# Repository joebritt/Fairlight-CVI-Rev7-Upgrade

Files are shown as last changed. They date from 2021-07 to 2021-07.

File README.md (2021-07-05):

# Fairlight-CVI-Rev7-Upgrade
Board set to upgrade a Rev5 Fairlight CVI to Rev7. This upgrade also eliminates the need for backup batteries.

See overview and installation guide [here](https://docs.google.com/document/d/1melksT-DwwU80pforqxVVXWFiSj0hJ2Gdj74KaH-A6M/edit?usp=sharing).

### All PCB designs were done in Eagle.

There are 4 different PCBs:</br>

One is the actual CVI06A, which mounts to the rear of the CVI. It is substantially smaller than the original CVI06.</br>

One is a small board which replaces the SRAM inside the CVI. This new board uses an FRAM to provide nonvolatile storage without a battery</br>

Two of these are just DIP-to-PLCC EPROM adapter boards.</br>
I made these because I had a bunch of PLCC 27C010 EPROMS I wanted to use! You can also just use 2716 and 27C128 EPROMs instead of these boards.

### EPROM Images

There are 4 EPROM images for inside the CVI unit. You'll replace the Rev5 EPROMs with parts programmed with these images:

CVI1R70.BIN and CVI2R70.BIN are images of Rev7 firmware EPROMs CVI1 and CVI2. These each go in a 27C128 16KB EPROM.

CVIHO52.BIN is the Horizonal timing control EPROM. This goes into a 2716 2KB EPROM.</br>
CVIVE50.BIN is the Vertical timing control EPROM. This goes into a 2716 2KB EPROM.

### PCB Designs

[27C128_adapter](https://oshpark.com/shared_projects/G9Li1LrF):</br>
Adapts a PLCC32 27C010 style memory to a DIP 27C128 style memory footprint.
Program just the bottom 16KB of the 27C010 before soldering it to the board.

[2716_adapter](https://oshpark.com/shared_projects/a2X7br2n):</br>
Adapts a PLCC32 27C010 style memory to a DIP 2716 style memory footprint.
Program just the bottom 2KB of the 27C010 before soldering it to the board.

[NoBattNVRAM](https://oshpark.com/shared_projects/FdYXVcIm):</br>
Replaces the CVI SRAM / 3V Lithium battery with FRAM. Nonvolatile memory, no battery needed.
A wire with a grabber clip is used to pick up the 6809 /E clock, which is needed to qualify accesses to the FRAM.

[CVI06A](https://oshpark.com/shared_projects/1o1eqgmB):</br>
The main attraction. Replacement for the original CVI06 expansion board. Smaller, easier to attach, and also uses FRAM for battery-free nonvolatile storage. Program the 27C010 for this board with the CVI43_CVI06A_v11 file in the low 32KB. This image contains the CVI3 and CVI4 Rev7 firmware EPROM images in a single part.

### Enclosure

CVI06A_box.stl and CVI06A_lid.stl can be 3D printed to make a small enclosure to protect the CVI06A PCB.</br>
The box is held together by friction. Note the capture features and line them up when closing.</br>
</br>
You can see the OnShape files used to create the enclosure box [here](https://cad.onshape.com/documents/24956ac0c366857a8c3e2111/w/adee8d27d6b88507ca310e0c/e/6c70102fddee723f7350afbb) and top [here](https://cad.onshape.com/documents/769b7af279cff9270446b3d7/w/f598dc3f7b092dcb1121a7f3/e/3ff1c2d9f7cff27cb58aa0f2).

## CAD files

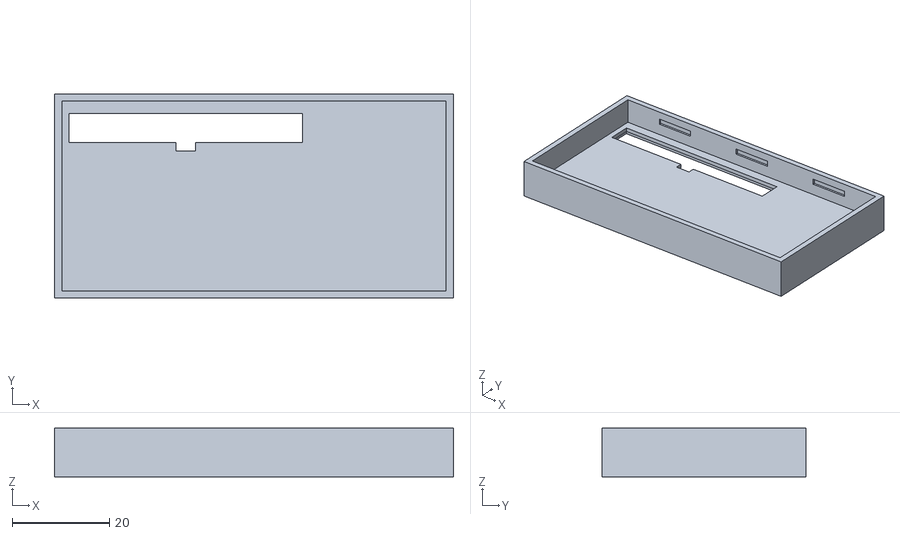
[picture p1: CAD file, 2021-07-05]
CVI06A_box.stl
82.0 x 42.0 x 10.0

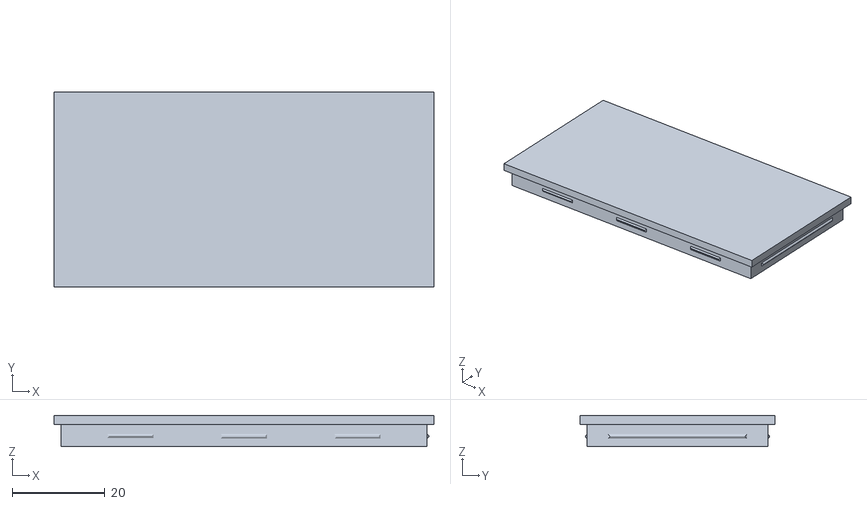
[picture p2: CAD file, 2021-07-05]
CVI06A_lid.stl
82.0 x 42.0 x 6.70

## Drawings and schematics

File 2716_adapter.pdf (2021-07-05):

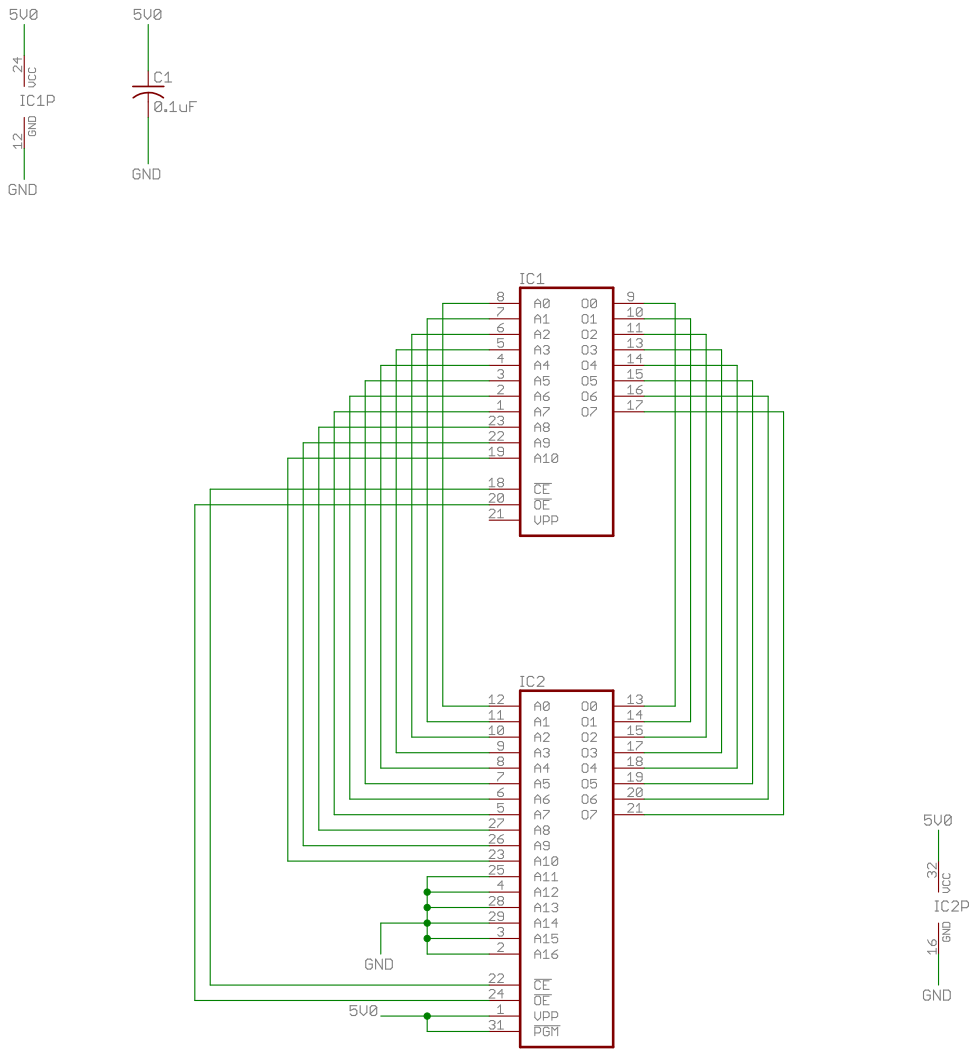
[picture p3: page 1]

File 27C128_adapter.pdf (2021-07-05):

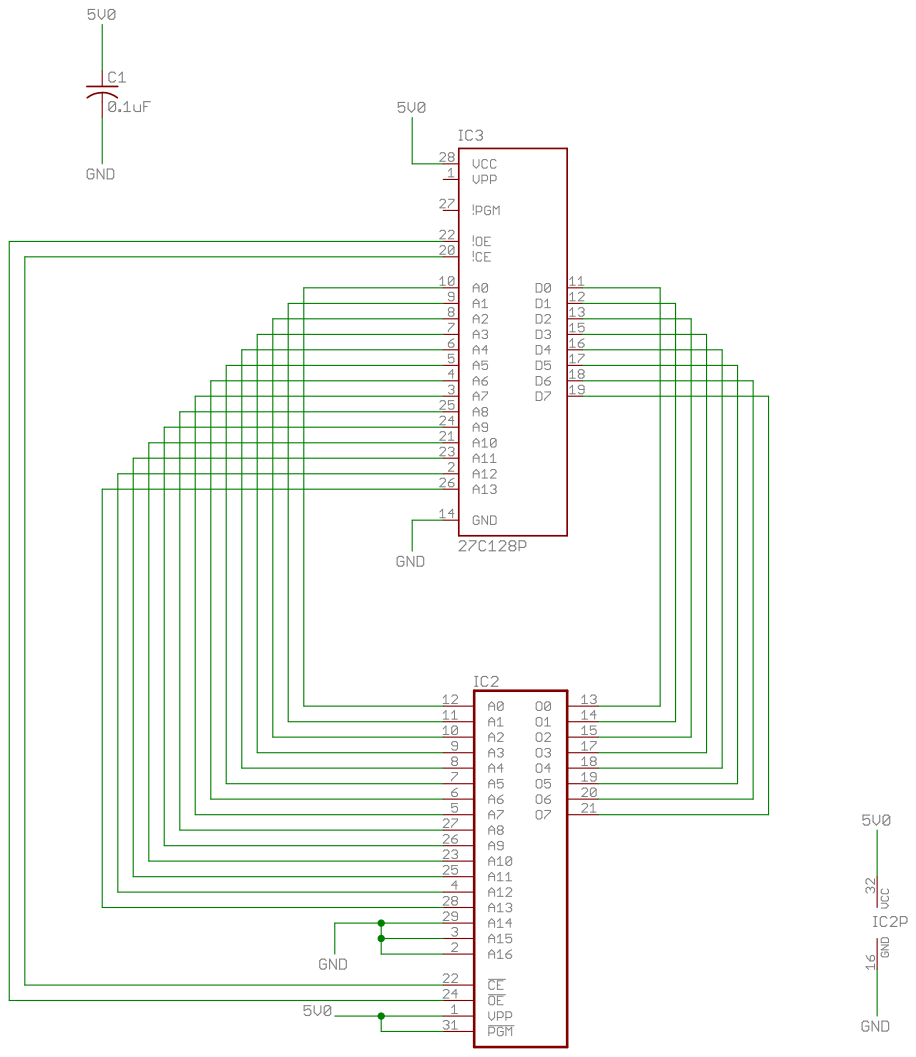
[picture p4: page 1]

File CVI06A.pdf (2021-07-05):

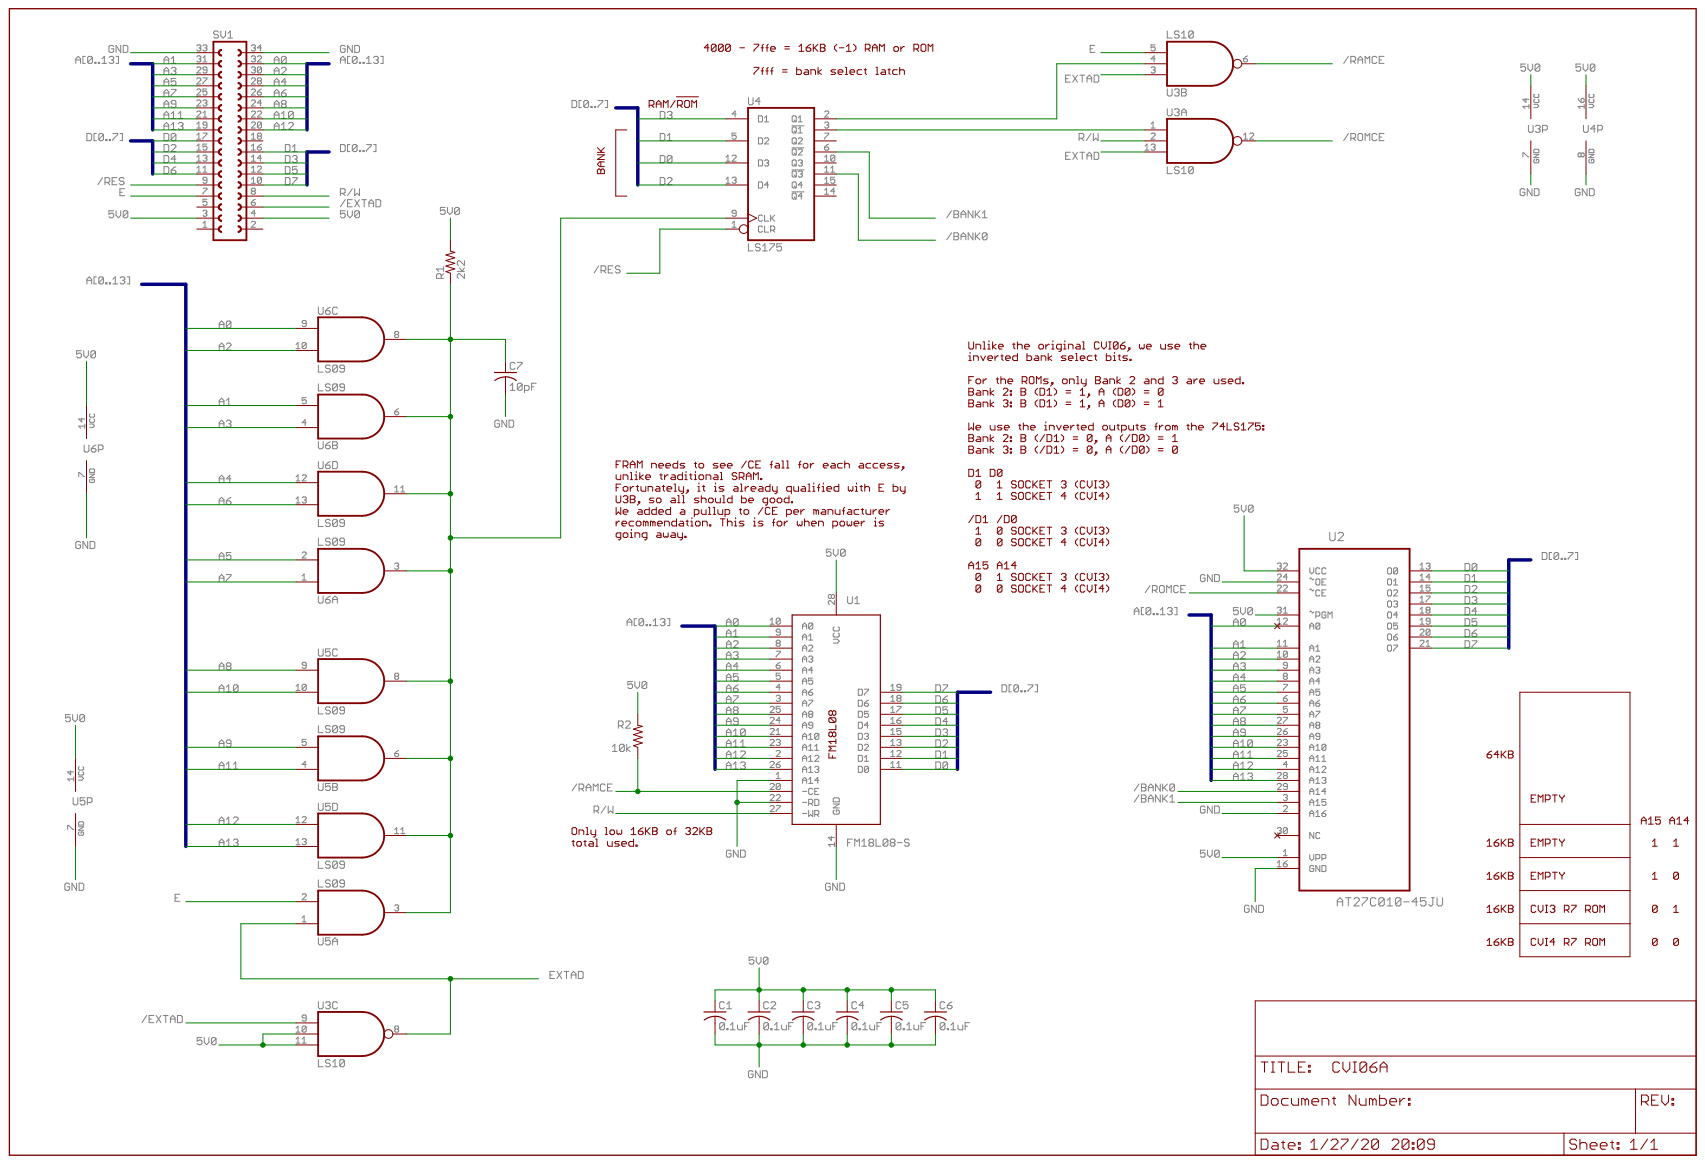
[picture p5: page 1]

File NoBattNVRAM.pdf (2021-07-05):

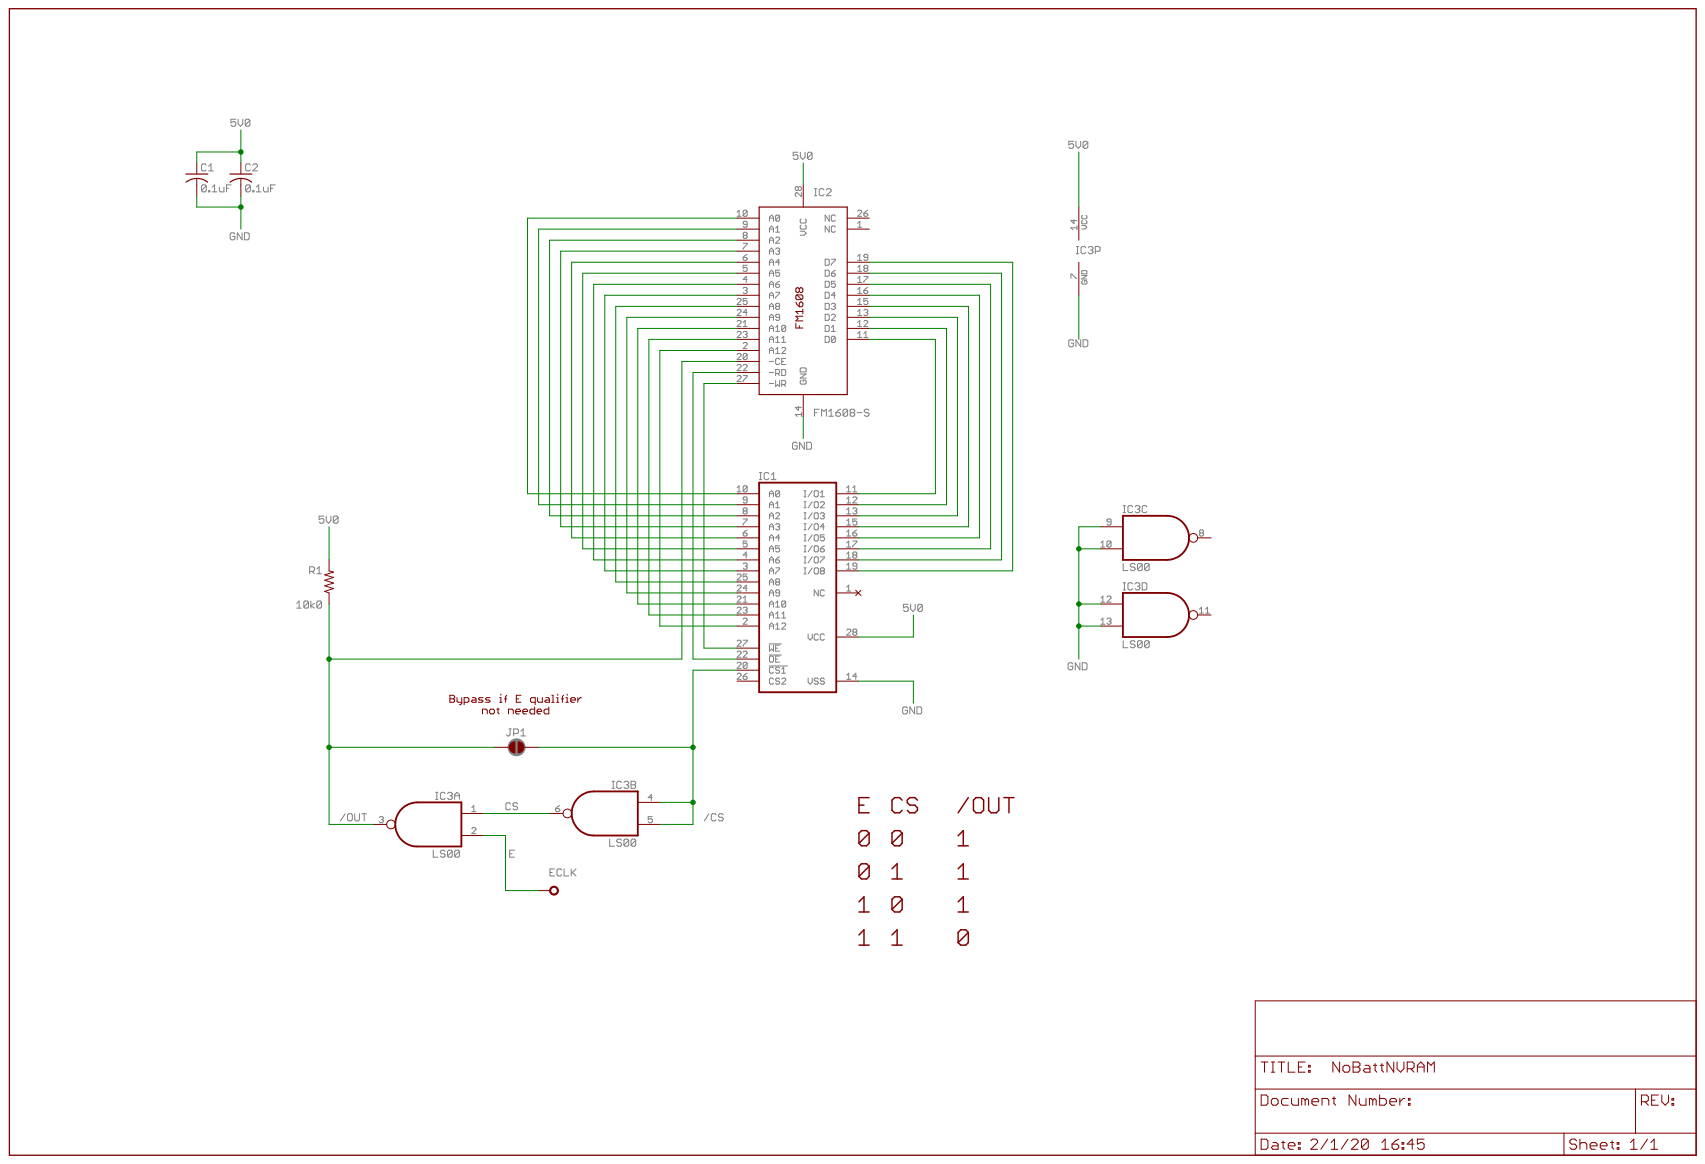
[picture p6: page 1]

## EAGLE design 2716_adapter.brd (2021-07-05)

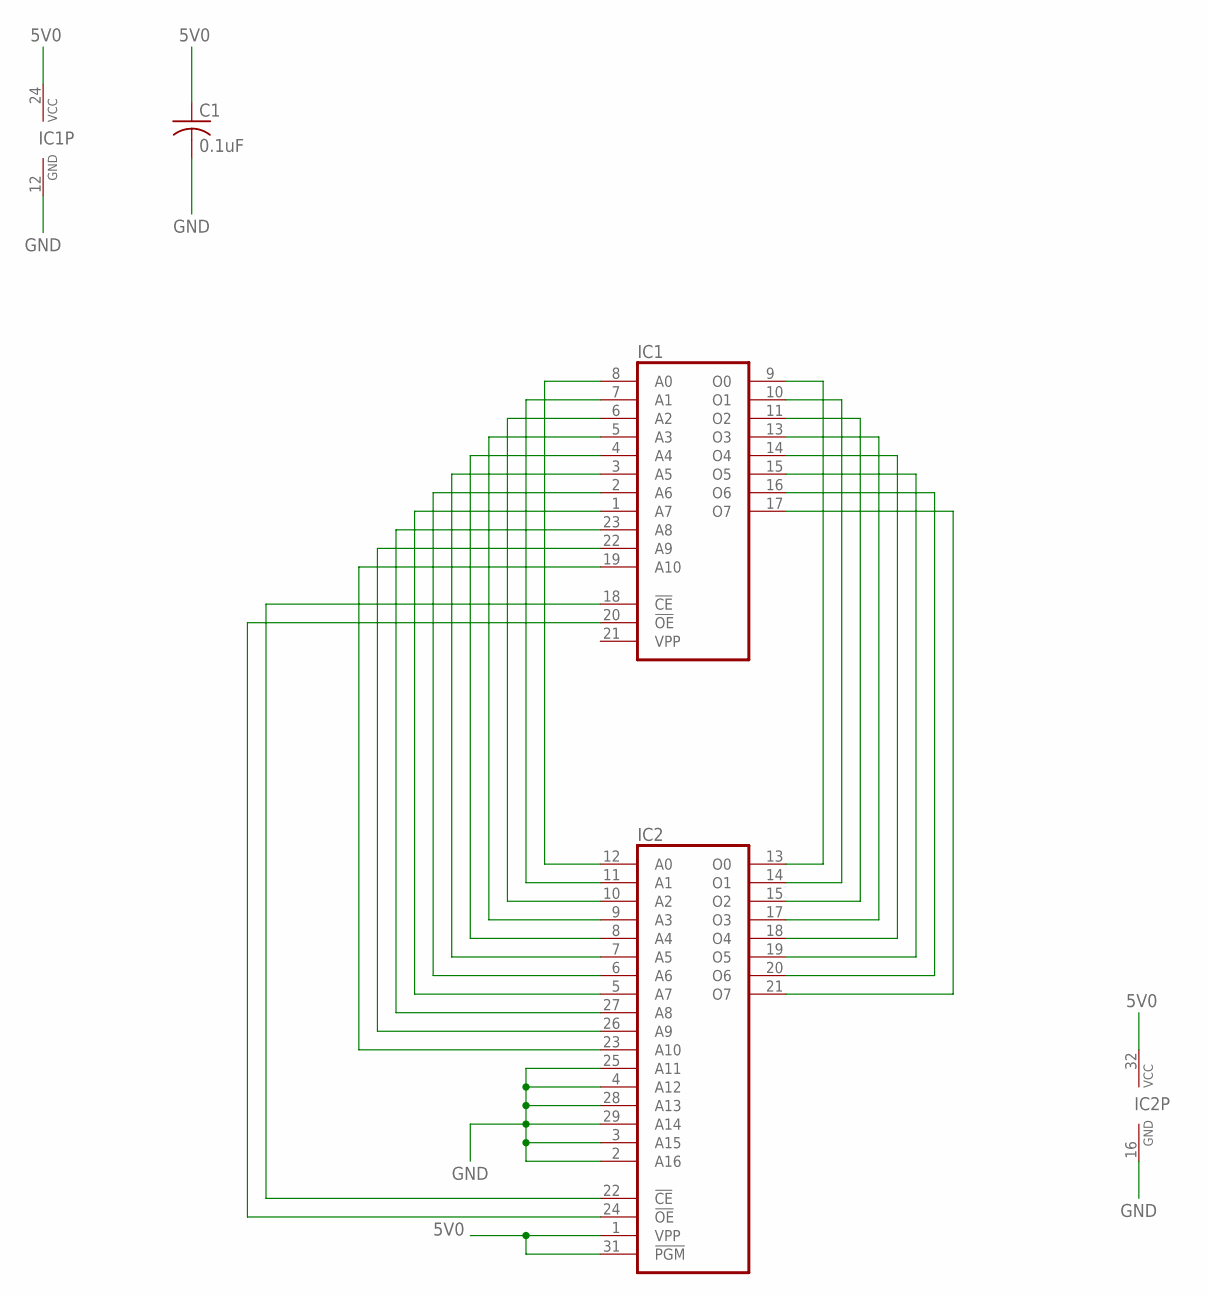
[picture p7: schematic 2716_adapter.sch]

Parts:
C1: 0.1uF; C0603K
IC1: 2716; DIL24
IC2: 27010PLCC32; PLCC32R

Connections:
5V0: C1.1, IC1.24 (VCC), IC2.1 (VPP), IC2.31 (!PGM), IC2.32 (VCC)
GND: C1.2, IC1.12 (GND), IC2.2 (A16), IC2.3 (A15), IC2.4 (A12), IC2.16 (GND), IC2.25 (A11), IC2.28 (A13), IC2.29 (A14)
unnamed: IC1.9 (O0), IC2.13 (O0)
unnamed: IC1.10 (O1), IC2.14 (O1)
unnamed: IC1.11 (O2), IC2.15 (O2)
unnamed: IC1.13 (O3), IC2.17 (O3)
unnamed: IC1.14 (O4), IC2.18 (O4)
unnamed: IC1.15 (O5), IC2.19 (O5)
unnamed: IC1.16 (O6), IC2.20 (O6)
unnamed: IC1.17 (O7), IC2.21 (O7)
unnamed: IC1.8 (A0), IC2.12 (A0)
unnamed: IC1.7 (A1), IC2.11 (A1)
unnamed: IC1.6 (A2), IC2.10 (A2)
unnamed: IC1.5 (A3), IC2.9 (A3)
unnamed: IC1.4 (A4), IC2.8 (A4)
unnamed: IC1.3 (A5), IC2.7 (A5)
unnamed: IC1.2 (A6), IC2.6 (A6)
unnamed: IC1.1 (A7), IC2.5 (A7)
unnamed: IC1.23 (A8), IC2.27 (A8)
unnamed: IC1.22 (A9), IC2.26 (A9)
unnamed: IC1.19 (A10), IC2.23 (A10)
unnamed: IC1.18 (!CE), IC2.22 (!CE)
unnamed: IC1.20 (!OE), IC2.24 (!OE)

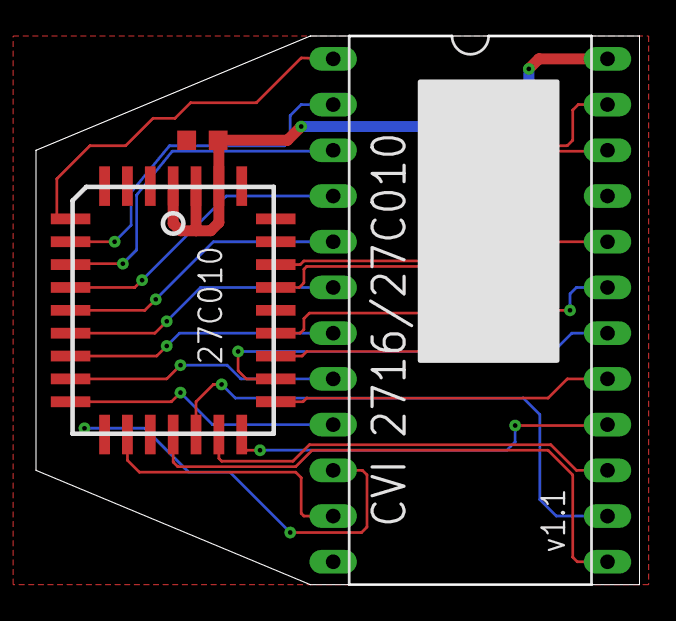
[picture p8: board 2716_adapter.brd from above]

Board: 2 copper layers, 33.5 x 30.5 mm, 3 parts (0 on the bottom side), 23 nets.

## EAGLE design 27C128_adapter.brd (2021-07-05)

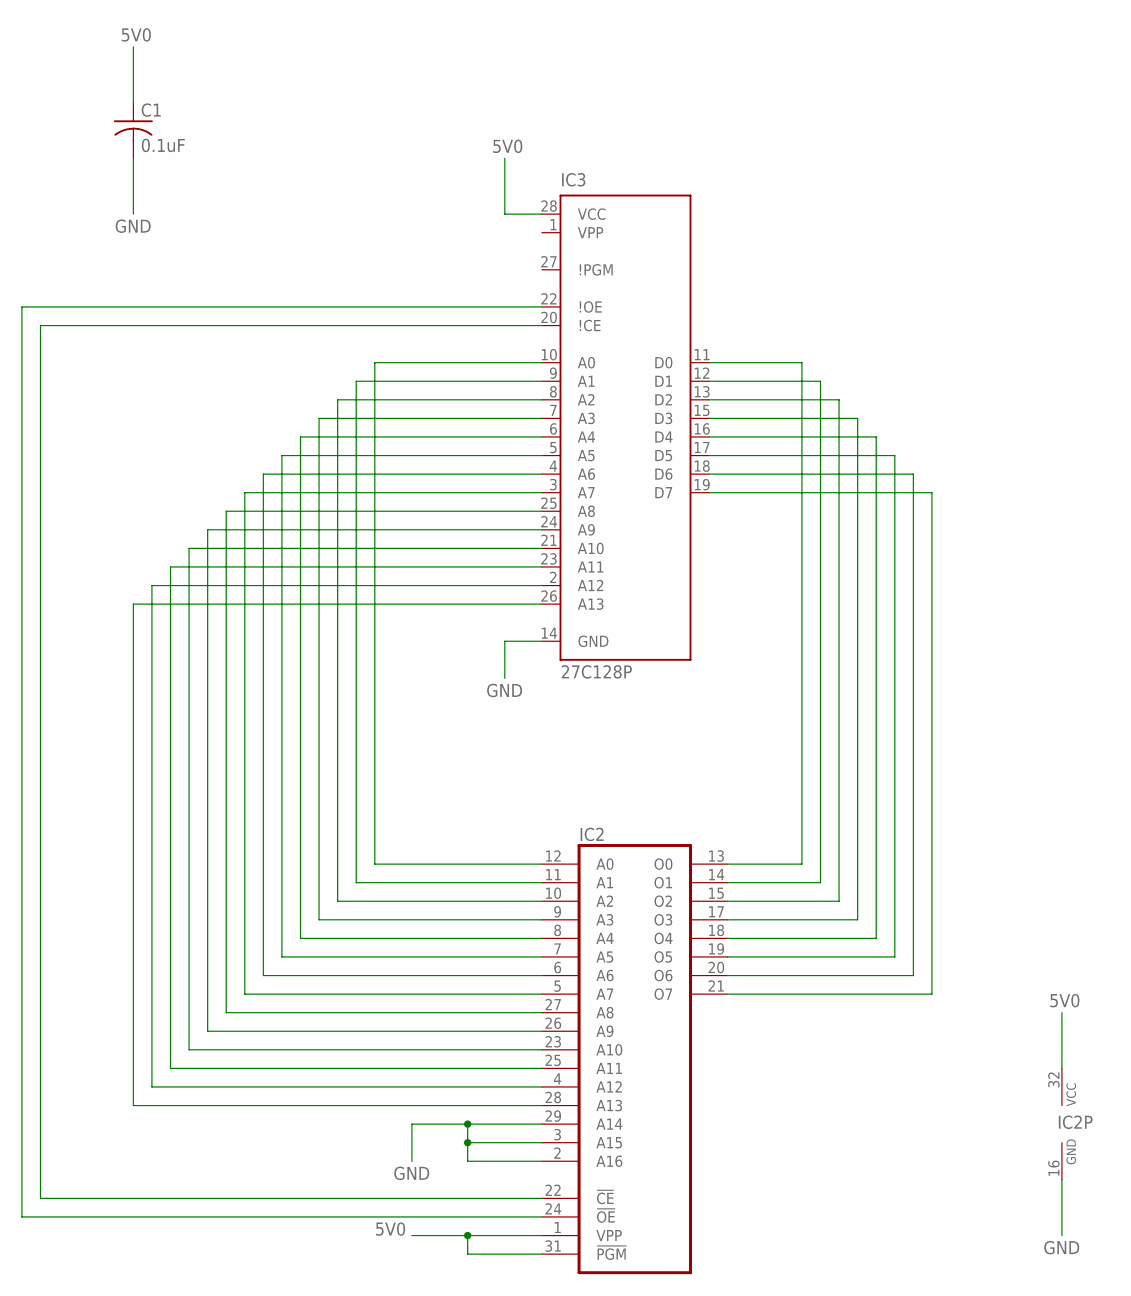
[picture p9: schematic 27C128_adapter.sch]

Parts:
C1: 0.1uF; C0603K
IC2: 27010PLCC32; PLCC32R
IC3: 27C128P; DIL28-6

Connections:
5V0: C1.1, IC2.1 (VPP), IC2.31 (!PGM), IC2.32 (VCC), IC3.28 (VCC)
GND: C1.2, IC2.2 (A16), IC2.3 (A15), IC2.16 (GND), IC2.29 (A14), IC3.14 (GND)
unnamed: IC2.25 (A11), IC3.23 (A11)
unnamed: IC2.4 (A12), IC3.2 (A12)
unnamed: IC2.28 (A13), IC3.26 (A13)
unnamed: IC2.17 (O3), IC3.15 (D3)
unnamed: IC2.18 (O4), IC3.16 (D4)
unnamed: IC2.19 (O5), IC3.17 (D5)
unnamed: IC2.20 (O6), IC3.18 (D6)
unnamed: IC2.21 (O7), IC3.19 (D7)
unnamed: IC2.12 (A0), IC3.10 (A0)
unnamed: IC2.11 (A1), IC3.9 (A1)
unnamed: IC2.14 (O1), IC3.12 (D1)
unnamed: IC2.13 (O0), IC3.11 (D0)
unnamed: IC2.15 (O2), IC3.13 (D2)
unnamed: IC2.22 (!CE), IC3.20 (\!CE)
unnamed: IC2.24 (!OE), IC3.22 (\!OE)
unnamed: IC2.10 (A2), IC3.8 (A2)
unnamed: IC2.9 (A3), IC3.7 (A3)
unnamed: IC2.8 (A4), IC3.6 (A4)
unnamed: IC2.7 (A5), IC3.5 (A5)
unnamed: IC2.6 (A6), IC3.4 (A6)
unnamed: IC2.5 (A7), IC3.3 (A7)
unnamed: IC2.27 (A8), IC3.25 (A8)
unnamed: IC2.26 (A9), IC3.24 (A9)
unnamed: IC2.23 (A10), IC3.21 (A10)

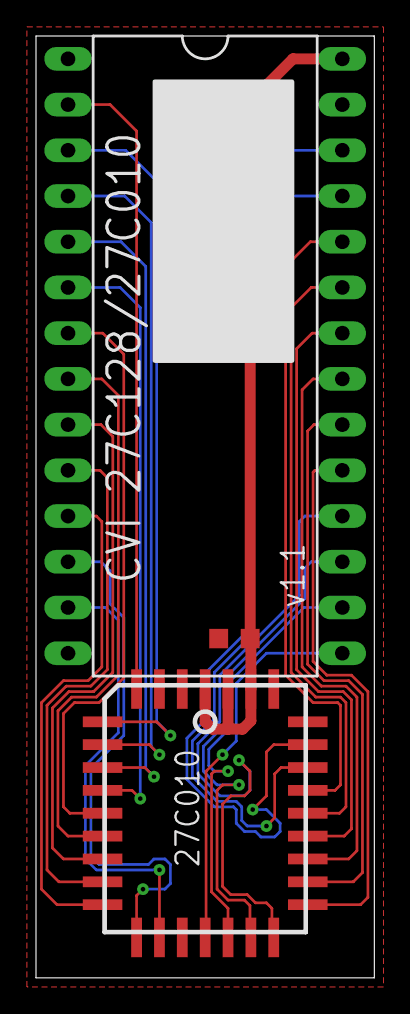
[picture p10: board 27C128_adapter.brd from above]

Board: 2 copper layers, 18.8 x 52.3 mm, 3 parts (0 on the bottom side), 26 nets.

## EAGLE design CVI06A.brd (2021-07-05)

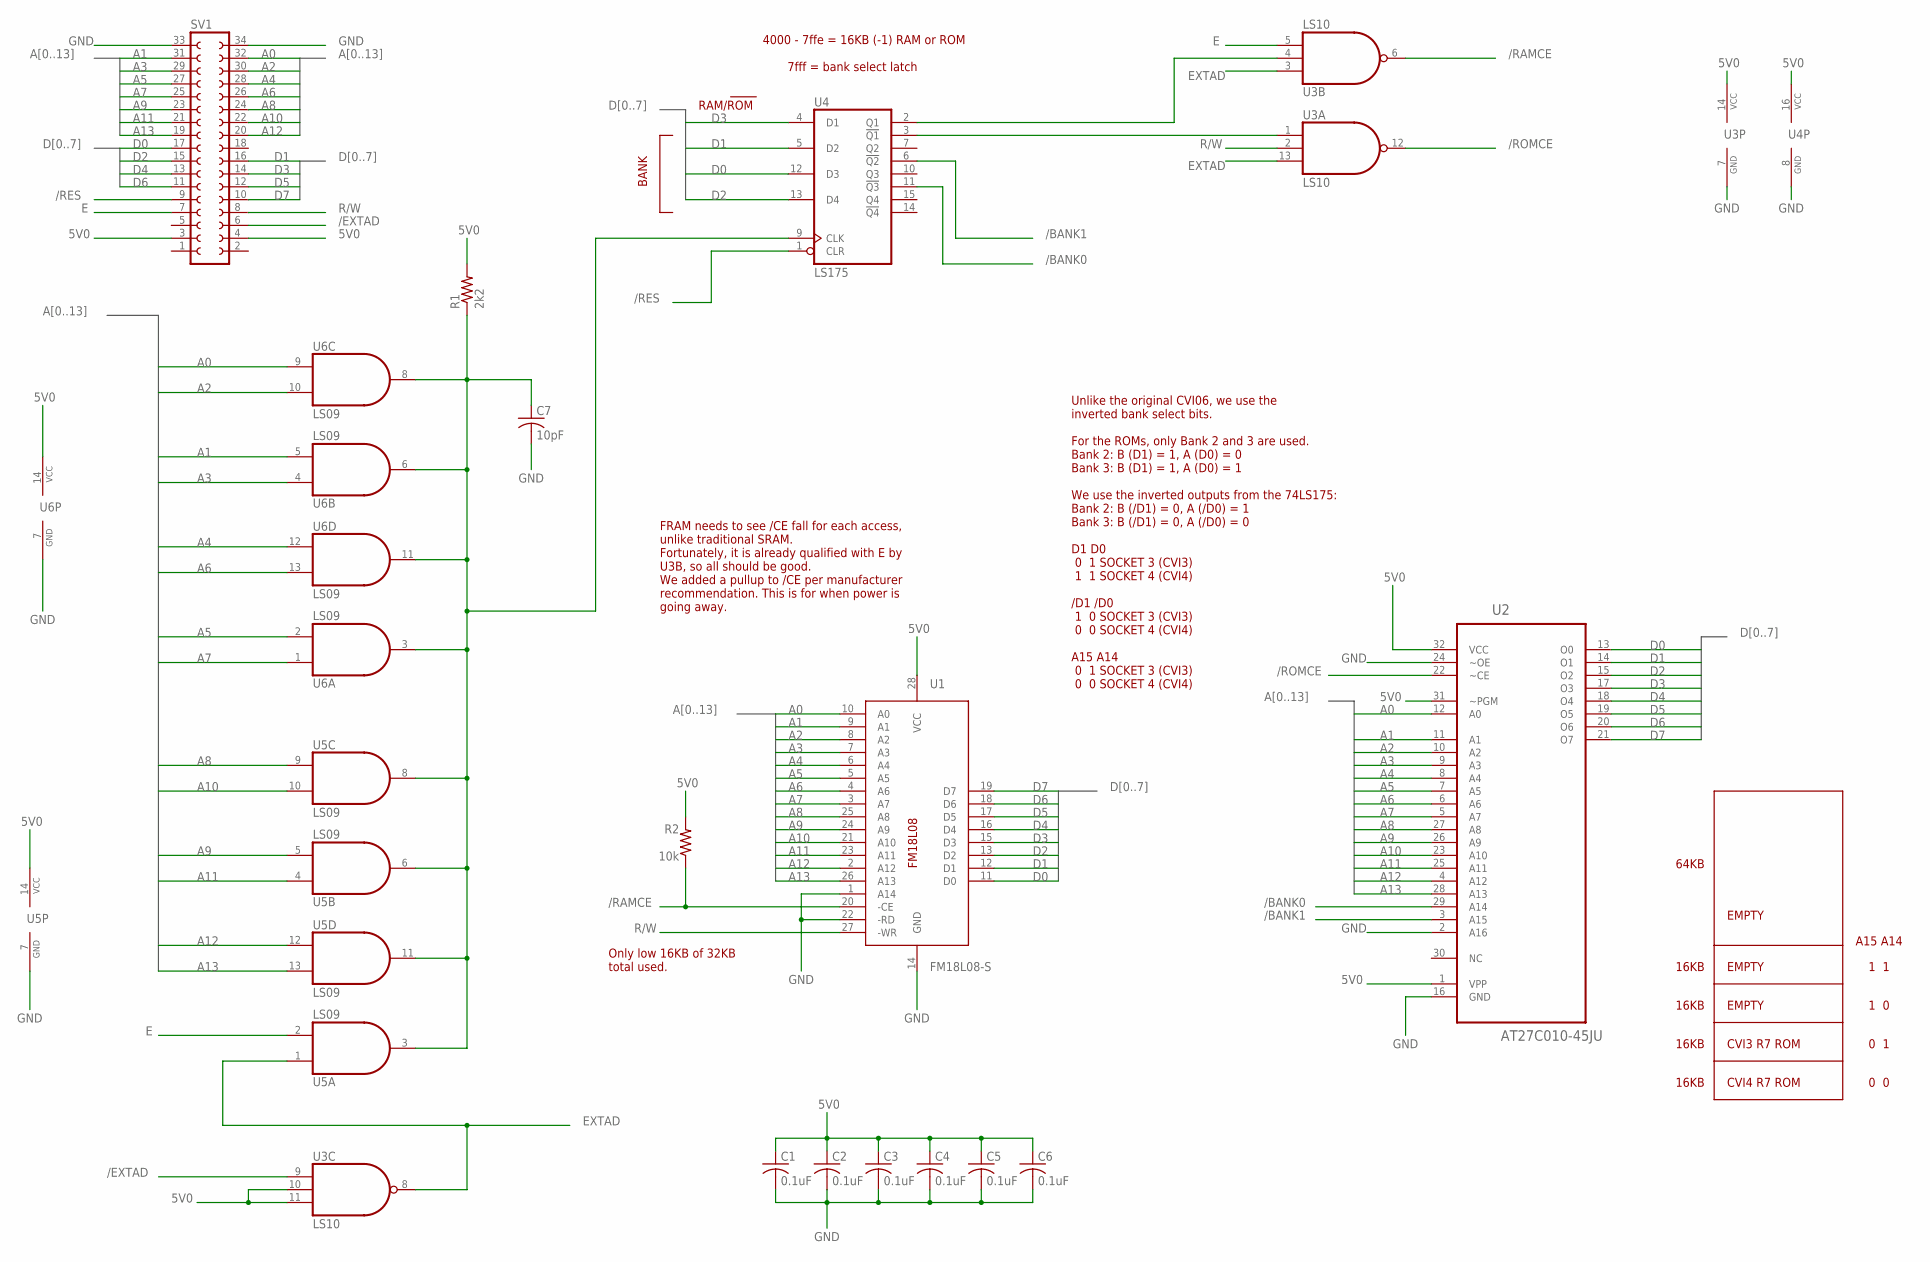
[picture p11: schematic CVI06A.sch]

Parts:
C1, C2, C3, C4, C5, C6: 0.1uF; C0603K
C7: 10pF; C0805
R1: 2k2; R0805
R2: 10k; R0805
SV1: FE17-2
U1: FM18L08-S; SO-28W
U2: AT27C010-45JU; PLCC127P1500X1250X355-32N
U3: LS10; SO14
U4: LS175; SO16
U5, U6: LS09; SO14

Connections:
5V0: C1.1, C2.1, C3.1, C4.1, C5.1, C6.1, R1.2, R2.2, SV1.3, SV1.4, U1.28 (VCC), U2.1 (VPP), U2.31 (~PGM), U2.32 (VCC), U3.10 (I1), U3.11 (I2), U3.14 (VCC), U4.16 (VCC), U5.14 (VCC), U6.14 (VCC)
/BANK0: U2.29 (A14), U4.11 (!Q3)
/BANK1: U2.3 (A15), U4.6 (!Q2)
/EXTAD: SV1.6, U3.9 (I0)
/RAMCE: R2.1, U1.20 (-CE), U3.6 (O)
/RES: SV1.9, U4.1 (CLR)
/ROMCE: U2.22 (~CE), U3.12 (O)
A0: SV1.32, U1.10 (A0), U2.12 (A0), U6.9 (I0)
A1: SV1.31, U1.9 (A1), U2.11 (A1), U6.5 (I1)
A2: SV1.30, U1.8 (A2), U2.10 (A2), U6.10 (I1)
A3: SV1.29, U1.7 (A3), U2.9 (A3), U6.4 (I0)
A4: SV1.28, U1.6 (A4), U2.8 (A4), U6.12 (I0)
A5: SV1.27, U1.5 (A5), U2.7 (A5), U6.2 (I1)
A6: SV1.26, U1.4 (A6), U2.6 (A6), U6.13 (I1)
A7: SV1.25, U1.3 (A7), U2.5 (A7), U6.1 (I0)
A8: SV1.24, U1.25 (A8), U2.27 (A8), U5.9 (I0)
A9: SV1.23, U1.24 (A9), U2.26 (A9), U5.5 (I1)
A10: SV1.22, U1.21 (A10), U2.23 (A10), U5.10 (I1)
A11: SV1.21, U1.23 (A11), U2.25 (A11), U5.4 (I0)
A12: SV1.20, U1.2 (A12), U2.4 (A12), U5.12 (I0)
A13: SV1.19, U1.26 (A13), U2.28 (A13), U5.13 (I1)
D0: SV1.17, U1.11 (D0), U2.13 (O0), U4.12 (D3)
D1: SV1.16, U1.12 (D1), U2.14 (O1), U4.5 (D2)
D2: SV1.15, U1.13 (D2), U2.15 (O2), U4.13 (D4)
D3: SV1.14, U1.15 (D3), U2.17 (O3), U4.4 (D1)
D4: SV1.13, U1.16 (D4), U2.18 (O4)
D5: SV1.12, U1.17 (D5), U2.19 (O5)
D6: SV1.11, U1.18 (D6), U2.20 (O6)
D7: SV1.10, U1.19 (D7), U2.21 (O7)
E: SV1.7, U3.5 (I2), U5.2 (I1)
EXTAD: U3.3 (I0), U3.8 (O), U3.13 (I2), U5.1 (I0)
GND: C1.2, C2.2, C3.2, C4.2, C5.2, C6.2, C7.2, SV1.33, SV1.34, U1.1 (A14), U1.14 (GND), U1.22 (-RD), U2.2 (A16), U2.16 (GND), U2.24 (~OE), U3.7 (GND), U4.8 (GND), U5.7 (GND), U6.7 (GND)
unnamed: C7.1, R1.1, U4.9 (CLK), U5.3 (O), U5.6 (O), U5.8 (O), U5.11 (O), U6.3 (O), U6.6 (O), U6.8 (O), U6.11 (O)
unnamed: U3.4 (I1), U4.2 (Q1)
unnamed: U3.1 (I0), U4.3 (!Q1)
R/W: SV1.8, U1.27 (-WR), U3.2 (I1)

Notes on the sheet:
RAM/ROM
BANK
Unlike the original CVI06, we use the inverted bank select bits. For the ROMs, only Bank 2 and 3 are used. Bank 2: B (D1) = 1, A (D0) = 0 Bank 3: B (D1) = 1, A (D0) = 1 We use the inverted outputs from the 74LS175: Bank 2: B (/D1) = 0, A (/D0) = 1 Bank 3: B (/D1) = 0, A (/D0) = 0 D1 D0 0 1 SOCKET 3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
FRAM needs to see /CE fall for each access, unlike traditional SRAM. Fortunately, it is already qualified with E by U3B, so all should be good. We added a pullup to /CE per manufacturer recommendation. This is for when power is going away.
16KB
EMPTY
CVI4 R7 ROM
CVI3 R7 ROM
64KB
Only low 16KB of 32KB total used.
0 0
0 1
1 0
1 1
A15 A14
4000 - 7ffe = 16KB (-1) RAM or ROM 7fff = bank select latch

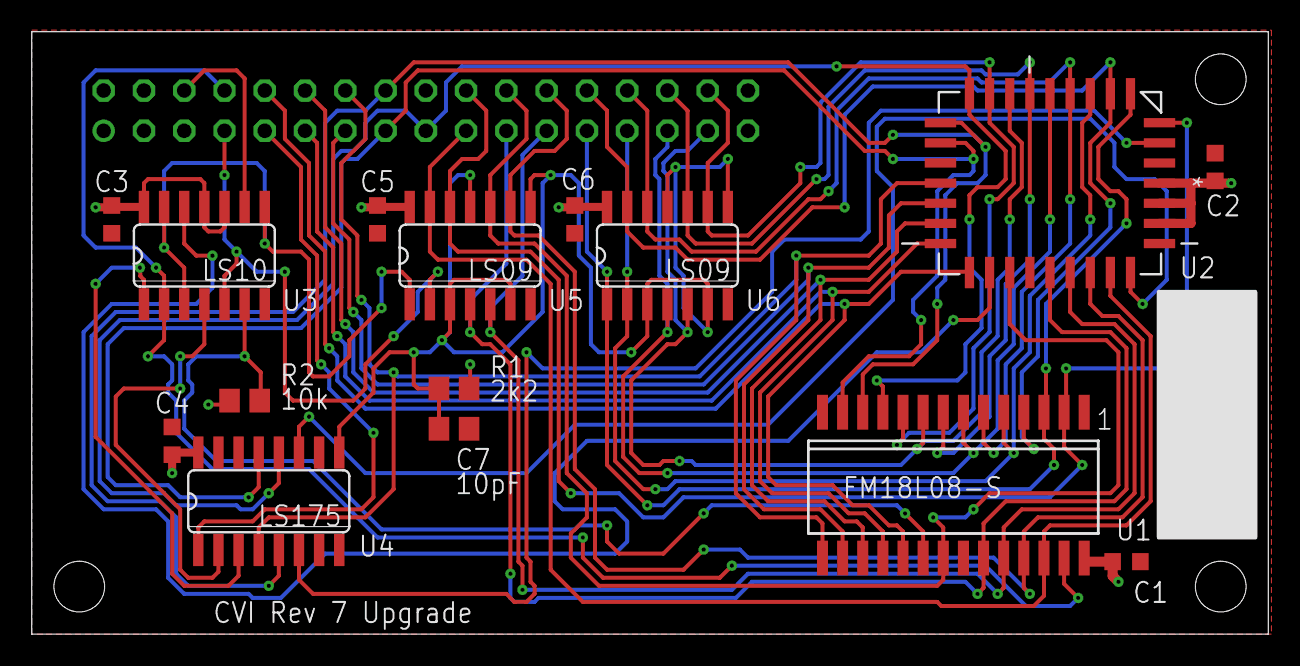
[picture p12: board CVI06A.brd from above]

Board: 2 copper layers, 78.0 x 38.0 mm, 16 parts (1 on the bottom side), 36 nets.

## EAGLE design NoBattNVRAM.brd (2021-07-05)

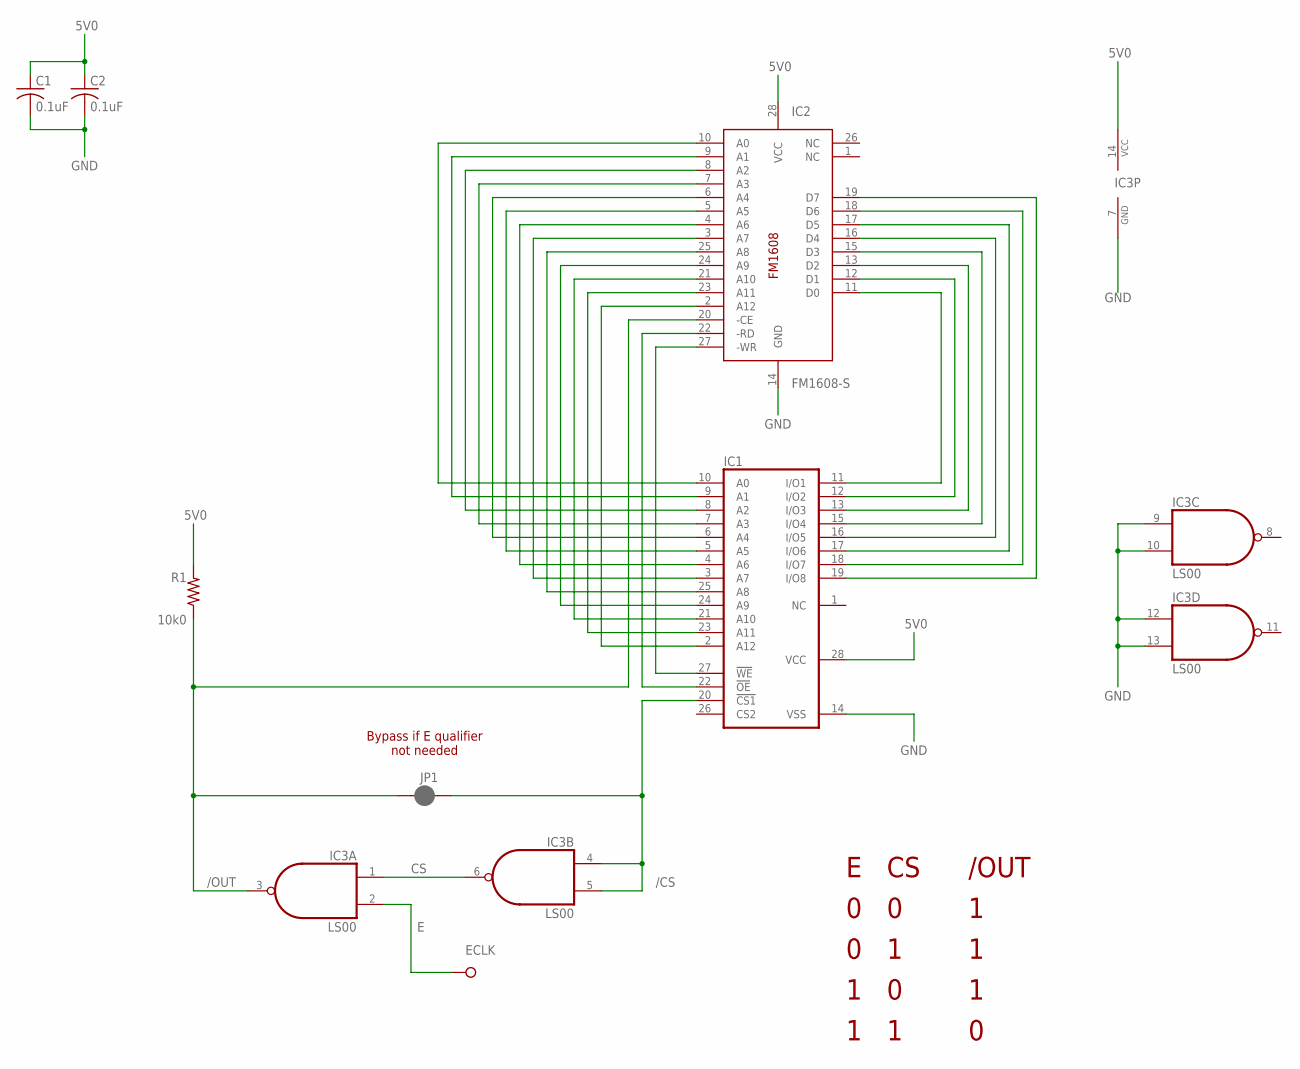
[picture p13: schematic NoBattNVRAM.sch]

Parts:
C1, C2: 0.1uF; C0603K
ECLK: JOE-TP-SHORT; JOE-TP-PKG
IC1: 6264A; DIL28-6
IC2: FM1608-S; SO-28W
IC3: LS00; SO14
JP1: JUMPER-PAD-2-NC_BY_PASTENO-SILK; PAD-JUMPER-2-NC_BY_PASTE_NO_SILK
R1: 10k0; R0805

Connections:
5V0: C1.1, C2.1, IC1.28 (VCC), IC2.28 (VCC), IC3.14 (VCC), R1.2
/CS: IC1.20 (!CS1), IC3.4 (I0), IC3.5 (I1), JP1.1
/OUT: IC2.20 (-CE), IC3.3 (O), JP1.2, R1.1
CS: IC3.1 (I0), IC3.6 (O)
E: ECLK.PAD1, IC3.2 (I1)
GND: C1.2, C2.2, IC1.14 (VSS), IC2.14 (GND), IC3.7 (GND), IC3.9 (I0), IC3.10 (I1), IC3.12 (I0), IC3.13 (I1)
unnamed: IC1.10 (A0), IC2.10 (A0)
unnamed: IC1.9 (A1), IC2.9 (A1)
unnamed: IC1.8 (A2), IC2.8 (A2)
unnamed: IC1.7 (A3), IC2.7 (A3)
unnamed: IC1.6 (A4), IC2.6 (A4)
unnamed: IC1.5 (A5), IC2.5 (A5)
unnamed: IC1.4 (A6), IC2.4 (A6)
unnamed: IC1.3 (A7), IC2.3 (A7)
unnamed: IC1.25 (A8), IC2.25 (A8)
unnamed: IC1.24 (A9), IC2.24 (A9)
unnamed: IC1.21 (A10), IC2.21 (A10)
unnamed: IC1.23 (A11), IC2.23 (A11)
unnamed: IC1.2 (A12), IC2.2 (A12)
unnamed: IC1.27 (!WE), IC2.27 (-WR)
unnamed: IC1.22 (!OE), IC2.22 (-RD)
unnamed: IC1.19 (I/O8), IC2.19 (D7)
unnamed: IC1.18 (I/O7), IC2.18 (D6)
unnamed: IC1.17 (I/O6), IC2.17 (D5)
unnamed: IC1.16 (I/O5), IC2.16 (D4)
unnamed: IC1.15 (I/O4), IC2.15 (D3)
unnamed: IC1.13 (I/O3), IC2.13 (D2)
unnamed: IC1.12 (I/O2), IC2.12 (D1)
unnamed: IC1.11 (I/O1), IC2.11 (D0)

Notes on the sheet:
/OUT
Bypass if E qualifier not needed

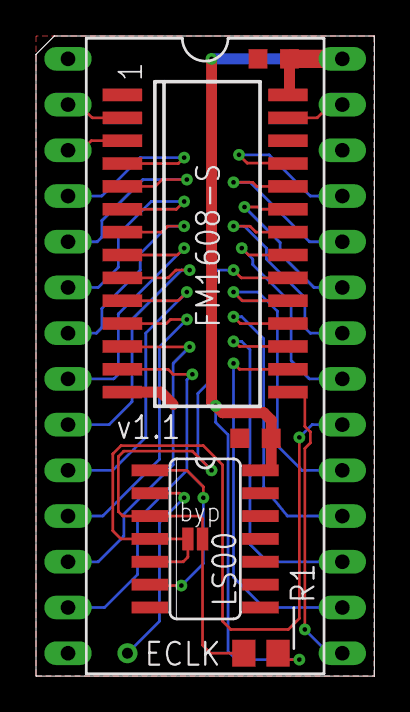
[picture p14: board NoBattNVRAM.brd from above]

Board: 2 copper layers, 18.8 x 35.6 mm, 8 parts (0 on the bottom side), 29 nets.

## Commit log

2021-07-05 Add files via upload
    Eagle schematics and board layout files for the Fairlight CVI Rev7 upgrade.
    Rev7 EPROM images also included.
    [2716_adapter.brd, 2716_adapter.sch, 27C128_adapter.brd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]
2021-07-05 Add files via upload
    PDFs of the 4 board schematics.

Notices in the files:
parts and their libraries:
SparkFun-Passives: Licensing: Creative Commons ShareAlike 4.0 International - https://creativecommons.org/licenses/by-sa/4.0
